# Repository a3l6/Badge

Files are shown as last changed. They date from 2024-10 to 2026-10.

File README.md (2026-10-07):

# Hack Canada Badge — v2 (RP2040 + E-Paper)

This was the first serious attempt at the Hack Canada badge before the design was later simplified into the battery-free NFC badges of v3 and v4.

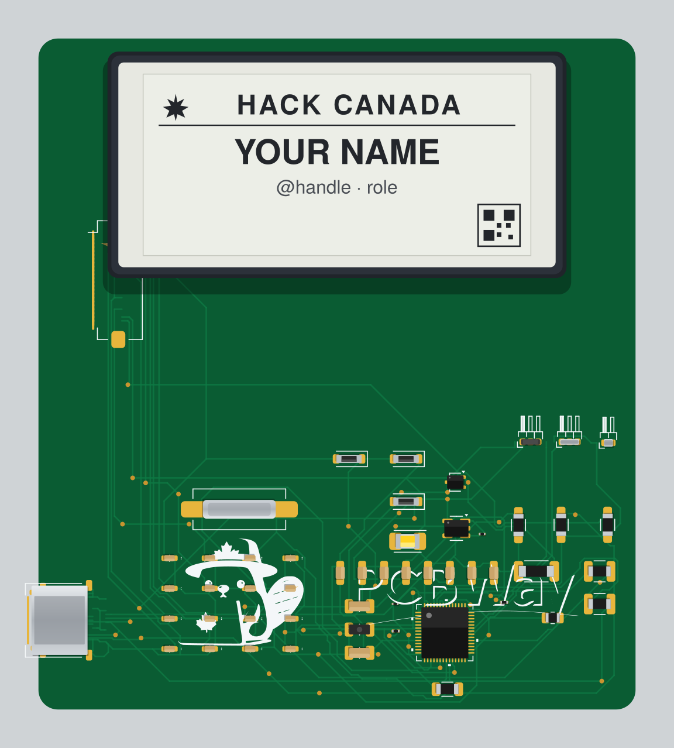
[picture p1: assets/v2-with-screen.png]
v2 badge — fully assembled with the e-paper display mounted


> The main render shows all 51 components placed at their real board positions with the 2.13" e-paper panel mounted on top. Renders are generated from this version's Gerber files (`pcb/prod/gerber/`); colours and the on-screen layout are illustrative.

---

## What it is

Where the later revisions stripped everything down to a passive NFC tag, v2 aimed high: a programmable badge with a screen you could actually put graphics and text on. It's essentially a tiny RP2040 development board in badge form, with an e-paper panel, USB-C for power and programming, and external flash for firmware and assets.

## How it works

```
USB-C ──► RP2040 ──► SPI ──► 2.13" e-paper display (GDEY0213F51)
            │
            ├──► QSPI ──► W25Q32 flash (firmware + images)
            ├──► 12 MHz crystal
            ├──► BOOT + RESET buttons, SWD header
            └──► status LED
```

Plug it in over USB-C, flash firmware to the RP2040 (BOOTSEL/UF2 or SWD), and drive the e-paper display to show a name, schedule, or artwork. The display holds its image with no power, which suits a badge that spends most of its life idle.

## Core components

| Function | Part |
| --- | --- |
| Microcontroller | RP2040 |
| Display | GDEY0213F51 — 2.13" e-paper / E-Ink (SEEKINK panel) |
| Flash | W25Q32JVSSIQ — 32 Mbit (4 MB) SPI/QSPI |
| Clock | 12 MHz crystal (FC4SDCBMF12.0-T1) |
| Power / data | USB Type-C |
| Indicator | VLMC3100-GS08 LED |
| Protection | LESD5D5.0CT1G TVS/ESD diodes |
| Controls | BOOT + RESET buttons, SWD debug header |

## Board

| Spec | Value |
| --- | --- |
| Dimensions | 77.05 × 86.55 mm |
| Layers | 2 |
| Thickness | 1.6 mm |
| Designed in | KiCad 8 |

| Front | Back |
| --- | --- |
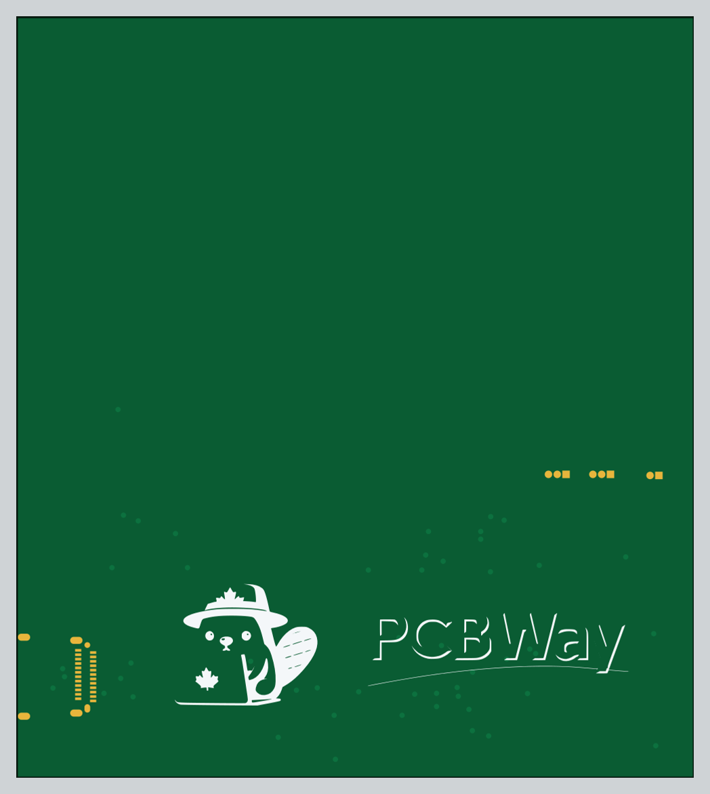
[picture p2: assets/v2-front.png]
Front
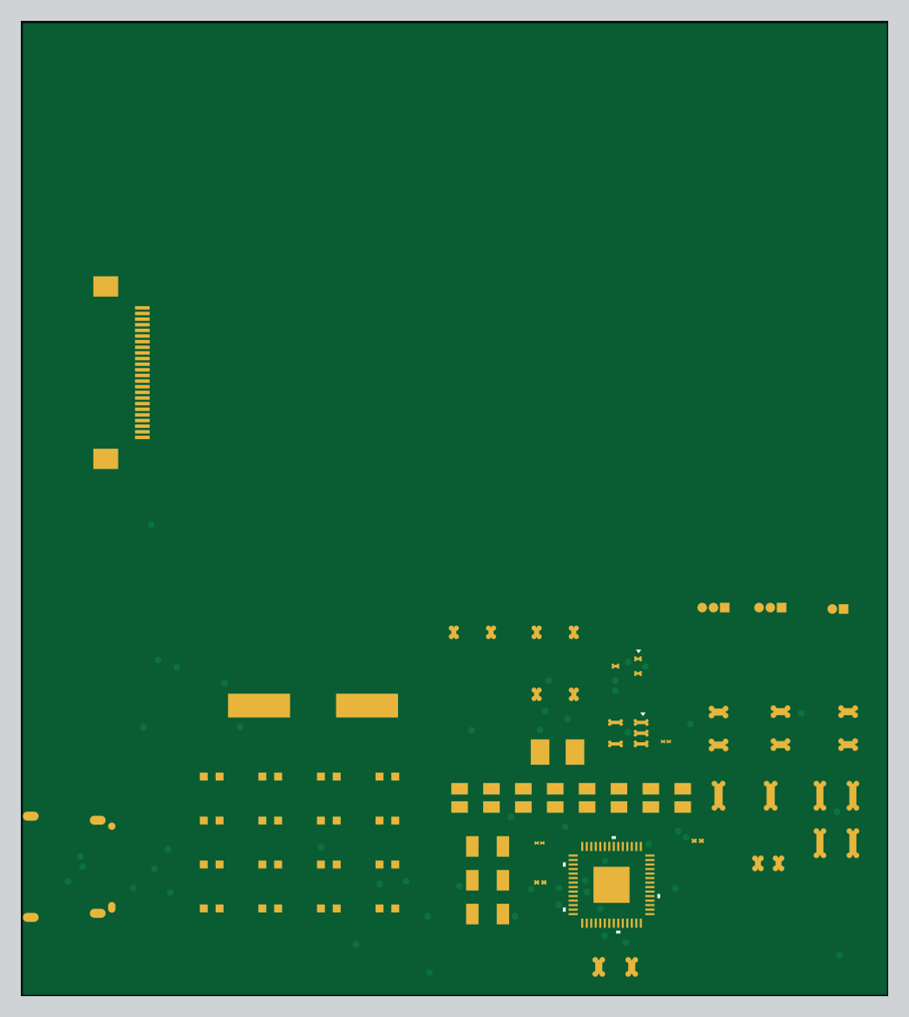
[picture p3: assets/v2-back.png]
Back
|  |  |

### Assembled (parts placed)

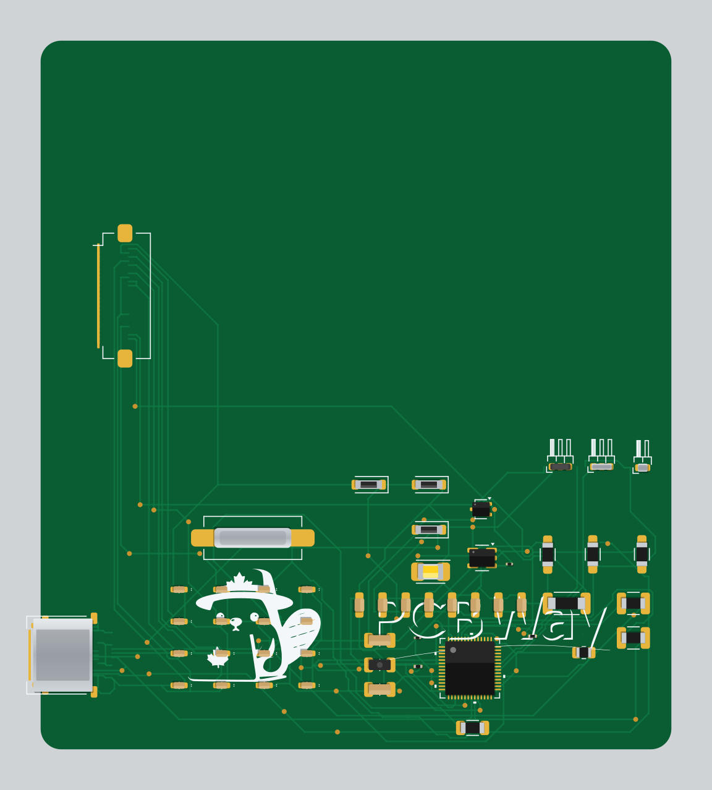
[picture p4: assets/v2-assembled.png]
v2 badge assembled


The e-paper panel (shown mounted in the main image at the top) connects over the FPC ribbon connector at the upper-left and sits above the board across the open top area, with the RP2040 and power circuitry tucked below it. The on-screen layout in that render is a placeholder mock-up, not artwork from the repo.

## Repository layout (v2 branch)

```
pcb/
├── badge.kicad_pcb / .kicad_sch / .kicad_pro   # main design
├── prod/gerber/                                # Gerbers, drills, gbrjob — ready to fab
├── badge-backups/                              # KiCad auto-backups
├── <component>/                                # per-part symbol/footprint/3D libraries
│   (RP2040, W25Q32, GDEY0213F51, crystal, LEDs, TVS, caps …)
└── assets/                                     # logos
GDEY0213F51.kicad_sym                           # e-paper display symbol
README.md
```

## Building your own

1. **Fabricate:** send `pcb/prod/gerber/` (or `badge-gerbers-and-designs.zip`) to your board house. It's a 2-layer, 1.6 mm board.
2. **Edit:** open `pcb/badge.kicad_pro` in KiCad 8 to modify the layout or schematic.
3. **Assemble & flash:** populate the parts, power over USB-C, and load RP2040 firmware via UF2 (BOOTSEL) or the SWD header. Then drive the GDEY0213F51 over SPI.

## History

v2 → **v3** (pivot to a battery-free NFC badge, adopted from the open "Opentaxus" design) → **v4** (streamlined 4-part NFC badge). See the `v3` and `v4` branches / READMEs.

## License

No license file is included, so all rights are reserved by default. Contact [@a3l6](https://github.com/a3l6) to discuss reuse.

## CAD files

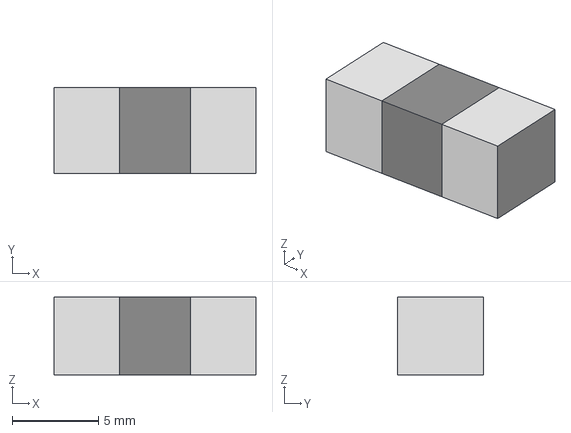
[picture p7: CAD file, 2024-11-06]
pcb/FC4SDCBMF12.0-T1/CRYSTAL_HC49SDLF_FXT.step
11.7 x 5.00 x 4.50 mm

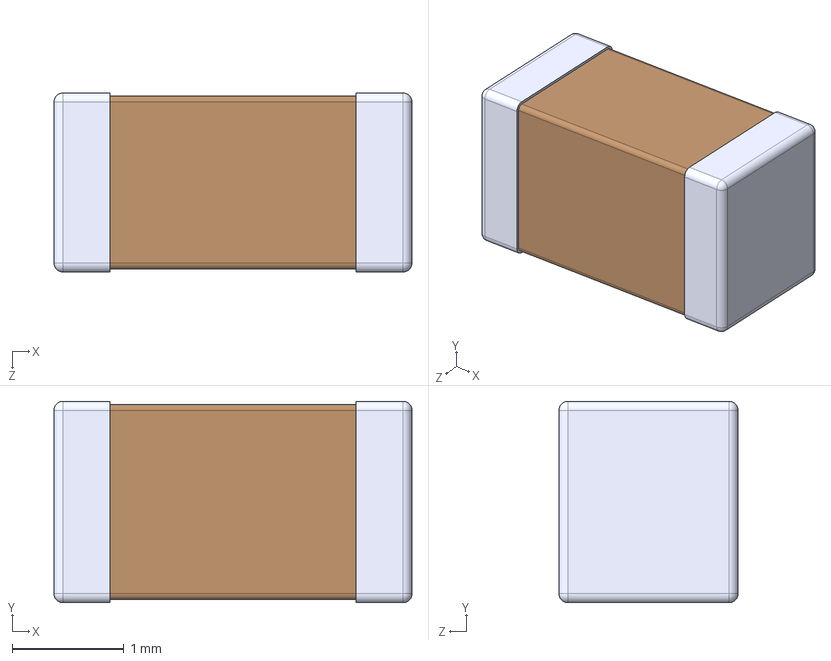
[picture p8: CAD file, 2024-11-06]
pcb/GMK316AB7475KLHT/3D/GMK316AB7475KLHT.stp
3.20 x 1.80 x 1.60 mm

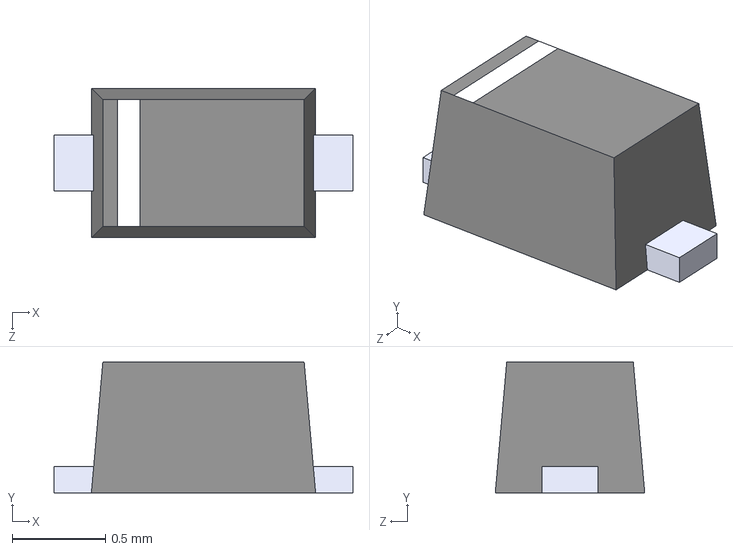
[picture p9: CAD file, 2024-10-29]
pcb/LESD5D5.0CT1G.step
1.60 x 0.7 x 0.8 mm

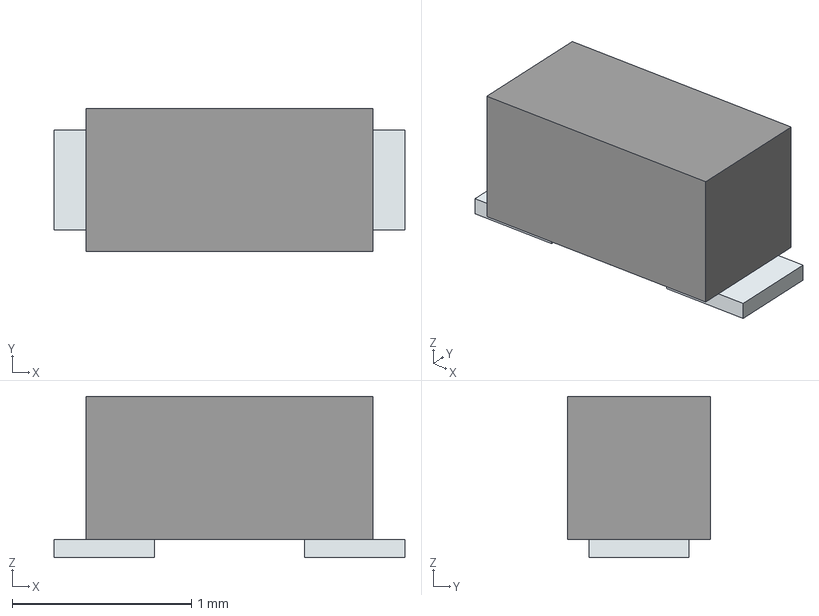
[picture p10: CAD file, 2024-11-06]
pcb/MAJCT168BB7105KTEA01/3D/MAJCT168BB7105KTEA01.stp
1.96 x 0.8 x 0.9 mm
Pins

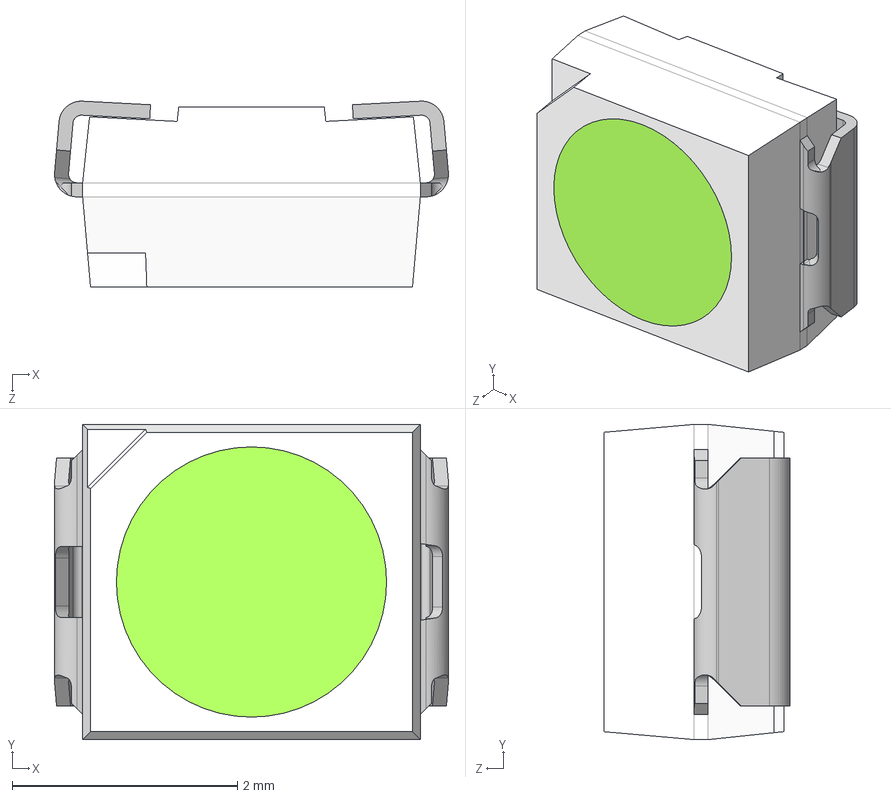
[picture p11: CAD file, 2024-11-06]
pcb/VLMC3100-GS08/3D/VLMC3100-GS08.stp
3.50 x 2.80 x 1.65 mm

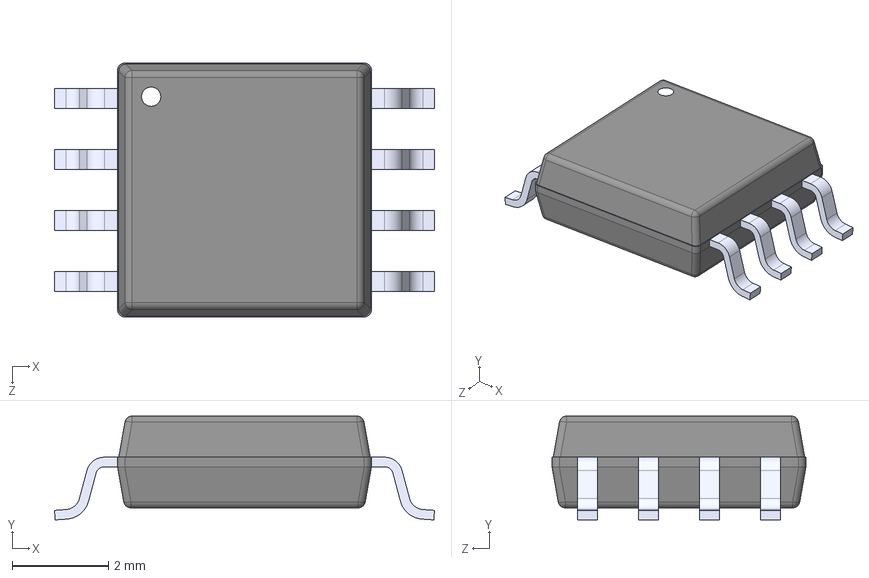
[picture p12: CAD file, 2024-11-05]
pcb/W25Q32JVSSIQ/W25Q32JVSSIQ.step
7.90 x 2.16 x 5.28 mm

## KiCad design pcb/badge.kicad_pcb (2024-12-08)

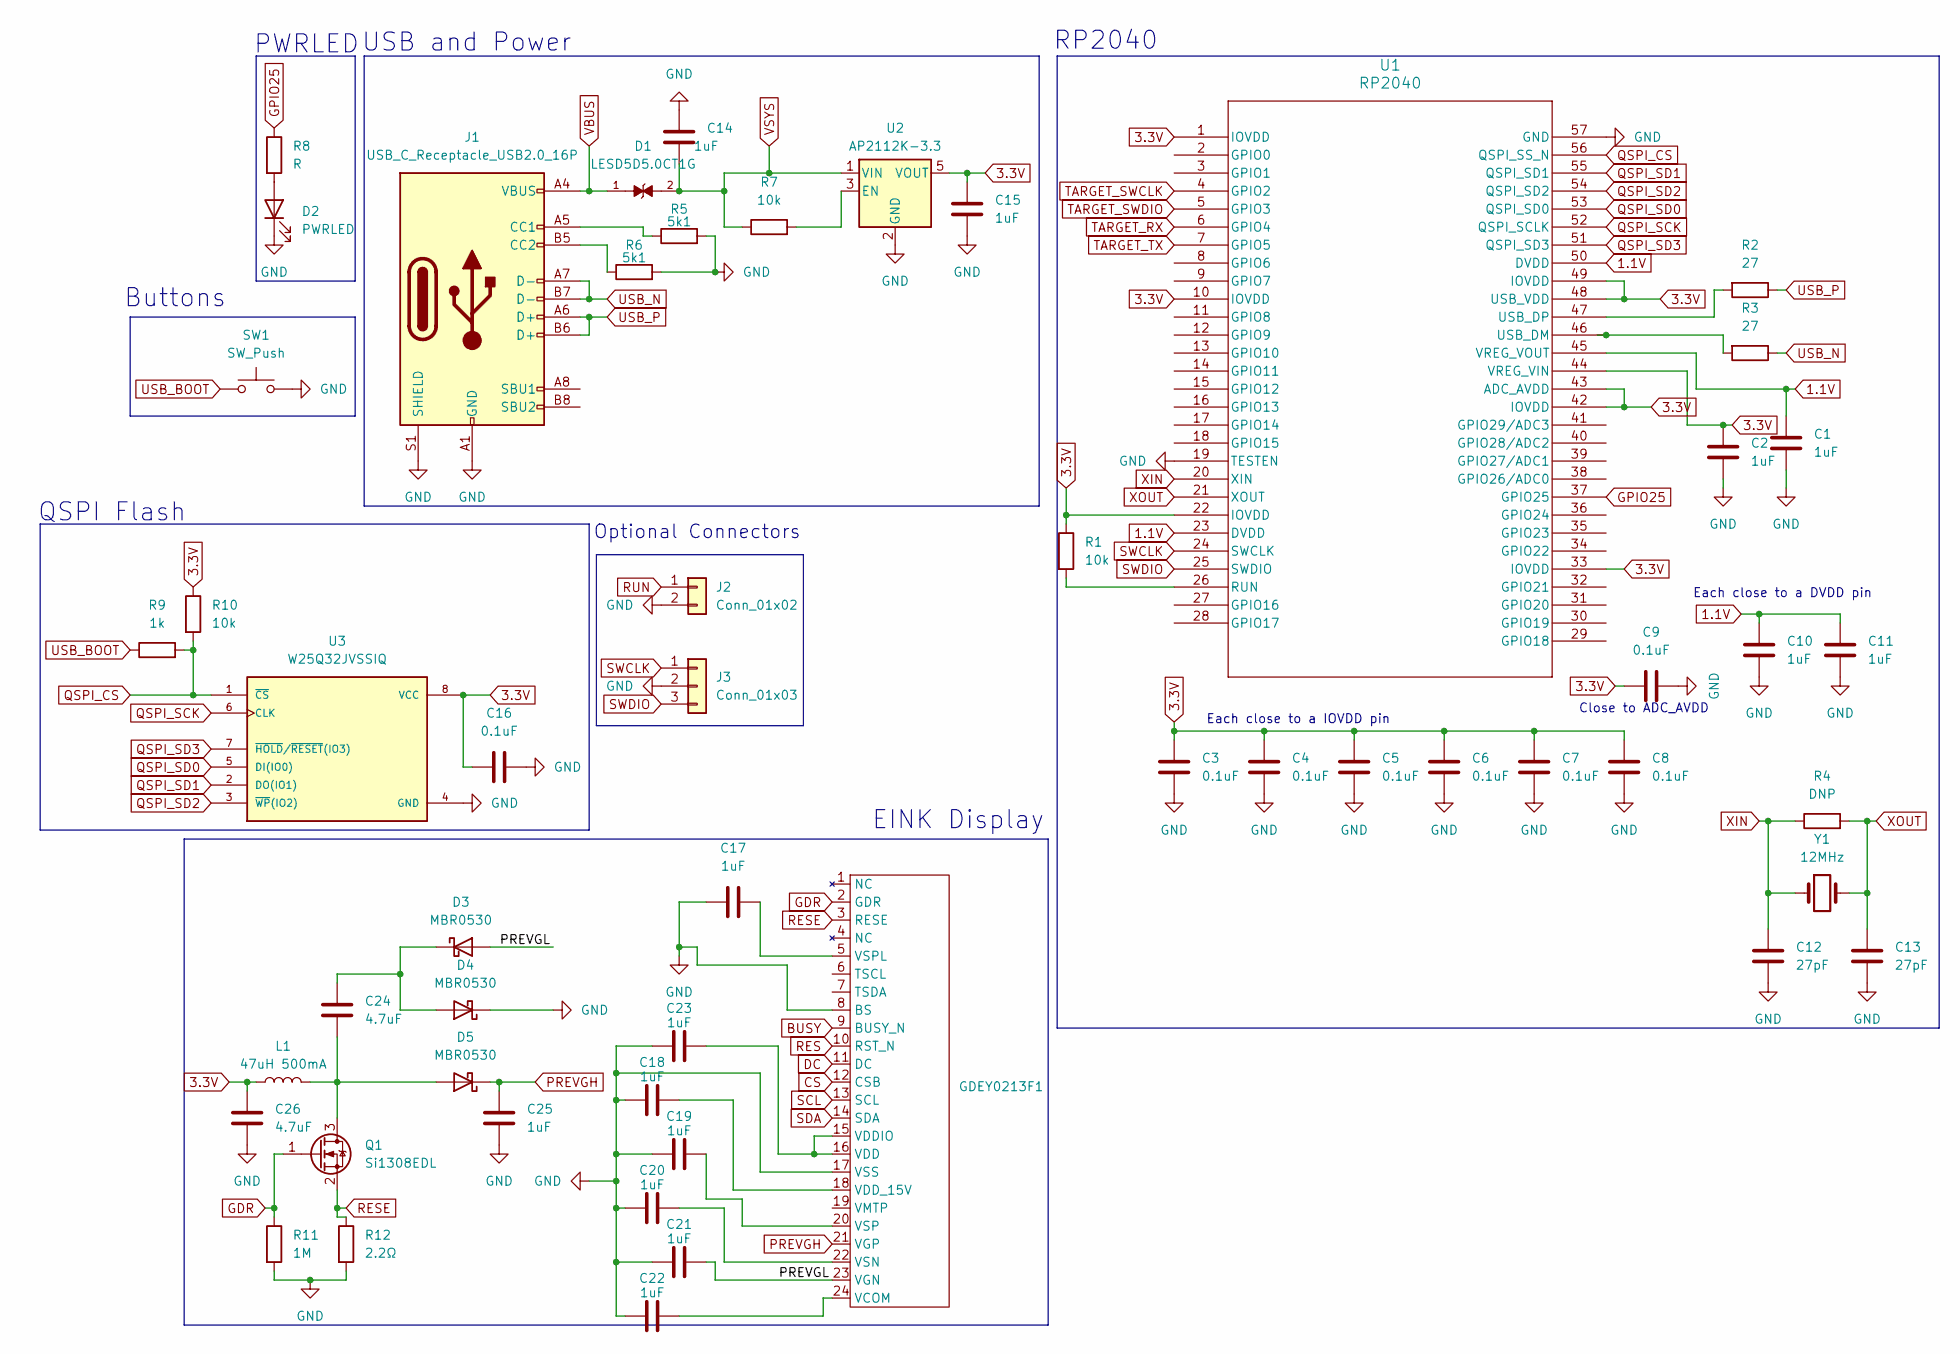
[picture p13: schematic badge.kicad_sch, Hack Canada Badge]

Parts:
C1, C2, C10, C11, C14, C15, C17, C18, C19, C20, C21, C22, C23, C25: 1uF; MAJx16
C3, C4, C5, C6, C7, C8, C9, C16: 0.1uF; CAPC2012X94N
C12, C13: 27pF; MAJx16
C24, C26: 4.7uF; CAPC3216X180N
D1: LESD5D5.0CT1G; TVS_LESD5D5.0CT1G; PARTREV O
D2: PWRLED; LEDM3528X185N
D3, D4, D5: MBR0530; D_SOD-123
GDEY0213F1: (no value)
J1: USB_C_Receptacle_USB2.0_16P; USB_C_Receptacle_Amphenol_12401610E4-2A
J2: Conn_01x02; PinHeader_1x02_P1.00mm_Horizontal
J3: Conn_01x03; PinHeader_1x03_P1.00mm_Horizontal
L1: 47uH 500mA; PinHeader_1x03_P1.00mm_Horizontal
Q1: Si1308EDL; SOT-323_SC-70
R1, R7, R10: 10k
R2, R3: 27
R4: DNP
R5, R6: 5k1
R8: R
R9: 1k
R11: 1M
R12: 2.2Ω
SW1: SW_Push
U1: RP2040; IC57_RP2040
U2: AP2112K-3.3; SOT-23-5
U3: W25Q32JVSSIQ; SOIC127P790X216-8N; M_PART_NUMBER W25QXX
Y1: 12MHz

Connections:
1.1V: C1.1, C10.1, C11.1, U1.23 (DVDD), U1.45 (VREG_VOUT), U1.50 (DVDD)
3.3V: C2.1, C3.1, C4.1, C5.1, C6.1, C7.1, C8.1, C9.1, C15.1, C16.1, C26.1, L1.1, R1.1, R10.1, U1.1 (IOVDD), U1.10 (IOVDD), U1.22 (IOVDD), U1.33 (IOVDD), U1.42 (IOVDD), U1.43 (ADC_AVDD), U1.44 (VREG_VIN), U1.48 (USB_VDD), U1.49 (IOVDD), U2.5 (VOUT), U3.8 (VCC)
/PREVGL: C21.2, D3.2 (A), GDEY0213F1.23 (VGN)
BUSY: GDEY0213F1.9 (BUSY_N)
CS: GDEY0213F1.12 (CSB)
DC: GDEY0213F1.11 (DC)
GDR: GDEY0213F1.2 (GDR), Q1.1 (G), R11.1
GND: C1.2, C2.2, C3.2, C4.2, C5.2, C6.2, C7.2, C8.2, C9.2, C10.2, C11.2, C12.2, C13.2, C14.1, C15.2, C16.2, C17.1, C18.1, C19.1, C20.1, C21.1, C22.1, C23.1, C25.2, C26.2, D2.1 (K), D4.1 (K), GDEY0213F1.8 (BS), GDEY0213F1.17 (VSS), J1.A1 (GND), J1.A12 (GND), J1.B1 (GND), J1.B12 (GND), J1.S1 (SHIELD), J2.2, J3.2, R5.2, R6.2, R11.2, R12.2, SW1.2, U1.19 (TESTEN), U1.57 (GND), U2.2 (GND), U3.4 (GND)
GPIO25: R8.1, U1.37 (GPIO25)
unnamed: D2.2 (A), R8.2
unnamed: C24.1, D3.1 (K), D4.2 (A)
unnamed: C24.2, D5.2 (A), L1.2, Q1.3 (D)
unnamed: C22.2, GDEY0213F1.24 (VCOM)
unnamed: C23.2, GDEY0213F1.15 (VDDIO), GDEY0213F1.16 (VDD)
unnamed: C18.2, GDEY0213F1.18 (VDD_15V)
unnamed: C20.2, GDEY0213F1.22 (VSN)
unnamed: C19.2, GDEY0213F1.20 (VSP)
unnamed: C17.2, GDEY0213F1.5 (VSPL)
unnamed: J1.A5 (CC1), R5.1
unnamed: J1.B5 (CC2), R6.1
unnamed: R1.2, U1.26 (RUN)
unnamed: R3.2, U1.46 (USB_DM)
unnamed: R2.2, U1.47 (USB_DP)
unnamed: R7.2, U2.3 (EN)
PREVGH: C25.1, D5.1 (K), GDEY0213F1.21 (VGP)
QSPI_CS: R9.2, R10.2, U1.56 (QSPI_SS_N), U3.1 (~CS)
QSPI_SCK: U1.52 (QSPI_SCLK), U3.6 (CLK)
QSPI_SD0: U1.53 (QSPI_SD0), U3.5 (DI(IO0))
QSPI_SD1: U1.55 (QSPI_SD1), U3.2 (DO(IO1))
QSPI_SD2: U1.54 (QSPI_SD2), U3.3 (~WP(IO2))
QSPI_SD3: U1.51 (QSPI_SD3), U3.7 (~HOLD/~RESET(IO3))
RES: GDEY0213F1.10 (RST_N)
RESE: GDEY0213F1.3 (RESE), Q1.2 (S), R12.1
RUN: J2.1
SCL: GDEY0213F1.13 (SCL)
SDA: GDEY0213F1.14 (SDA)
SWCLK: J3.1, U1.24 (SWCLK)
SWDIO: J3.3, U1.25 (SWDIO)
TARGET_RX: U1.6 (GPIO4)
TARGET_SWCLK: U1.4 (GPIO2)
TARGET_SWDIO: U1.5 (GPIO3)
TARGET_TX: U1.7 (GPIO5)
USB_BOOT: R9.1, SW1.1
USB_N: J1.A7 (D-), J1.B7 (D-), R3.1
USB_P: J1.A6 (D+), J1.B6 (D+), R2.1
VBUS: D1.1, J1.A4 (VBUS), J1.A9 (VBUS), J1.B4 (VBUS), J1.B9 (VBUS)
VSYS: C14.2, D1.2, R7.1, U2.1 (VIN)
XIN: C12.1, R4.1, U1.20 (XIN), Y1.1
XOUT: C13.1, R4.2, U1.21 (XOUT), Y1.2

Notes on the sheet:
EINK Display
USB and Power
Optional Connectors
Close to ADC_AVDD
Each close to a IOVDD pin
Buttons
Each close to a DVDD pin
RP2040
PWRLED
QSPI Flash

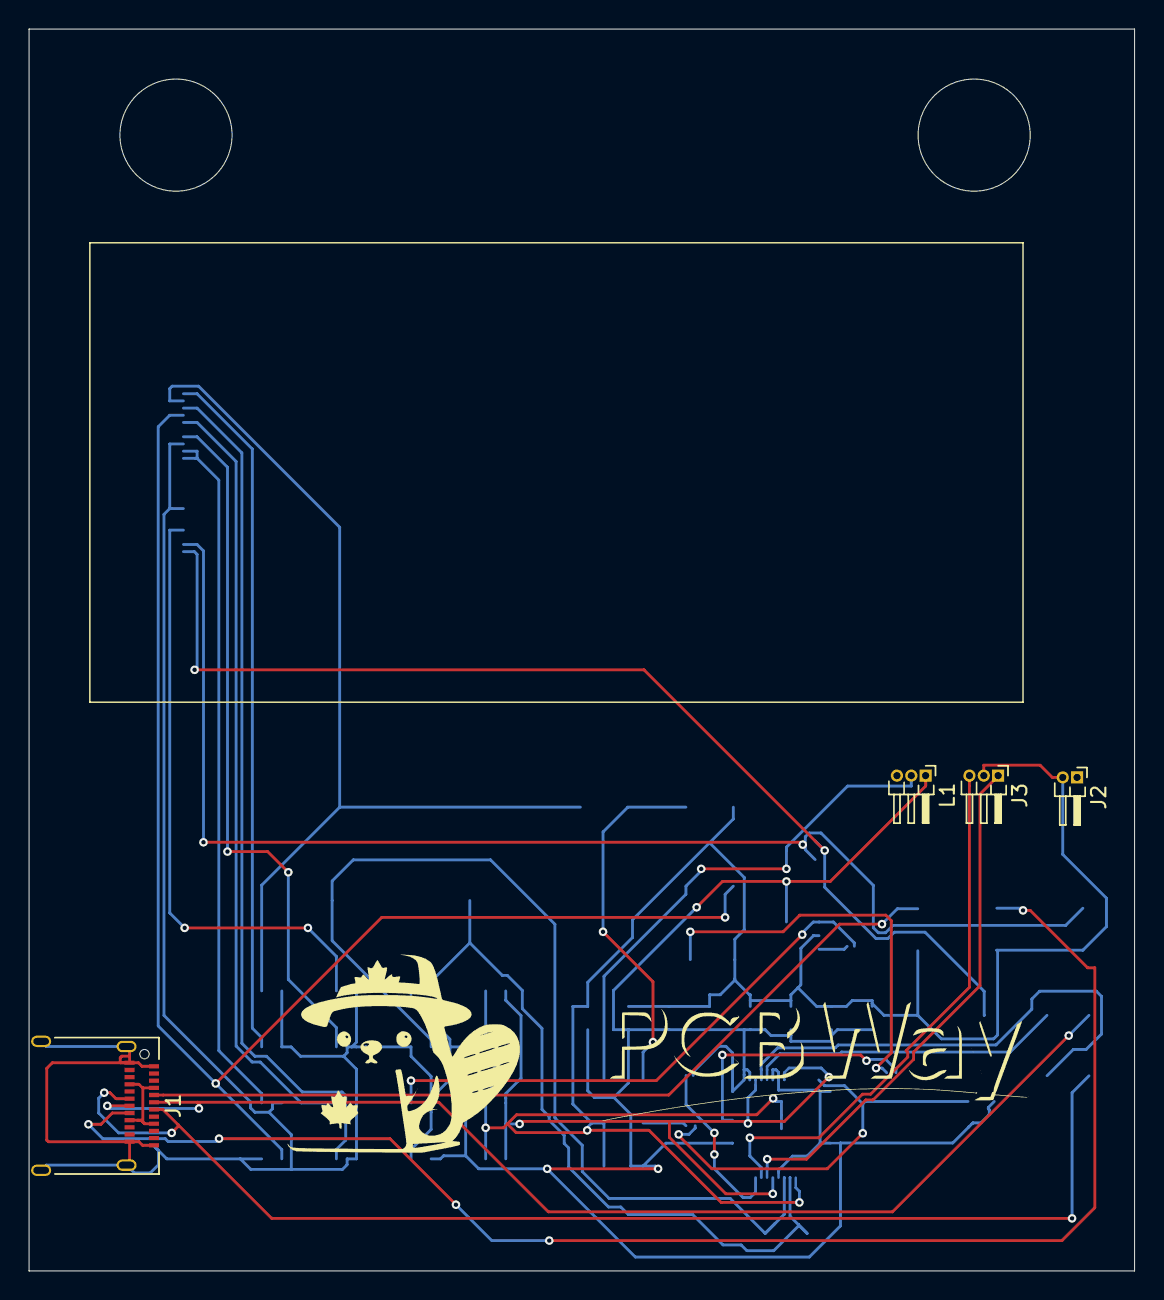
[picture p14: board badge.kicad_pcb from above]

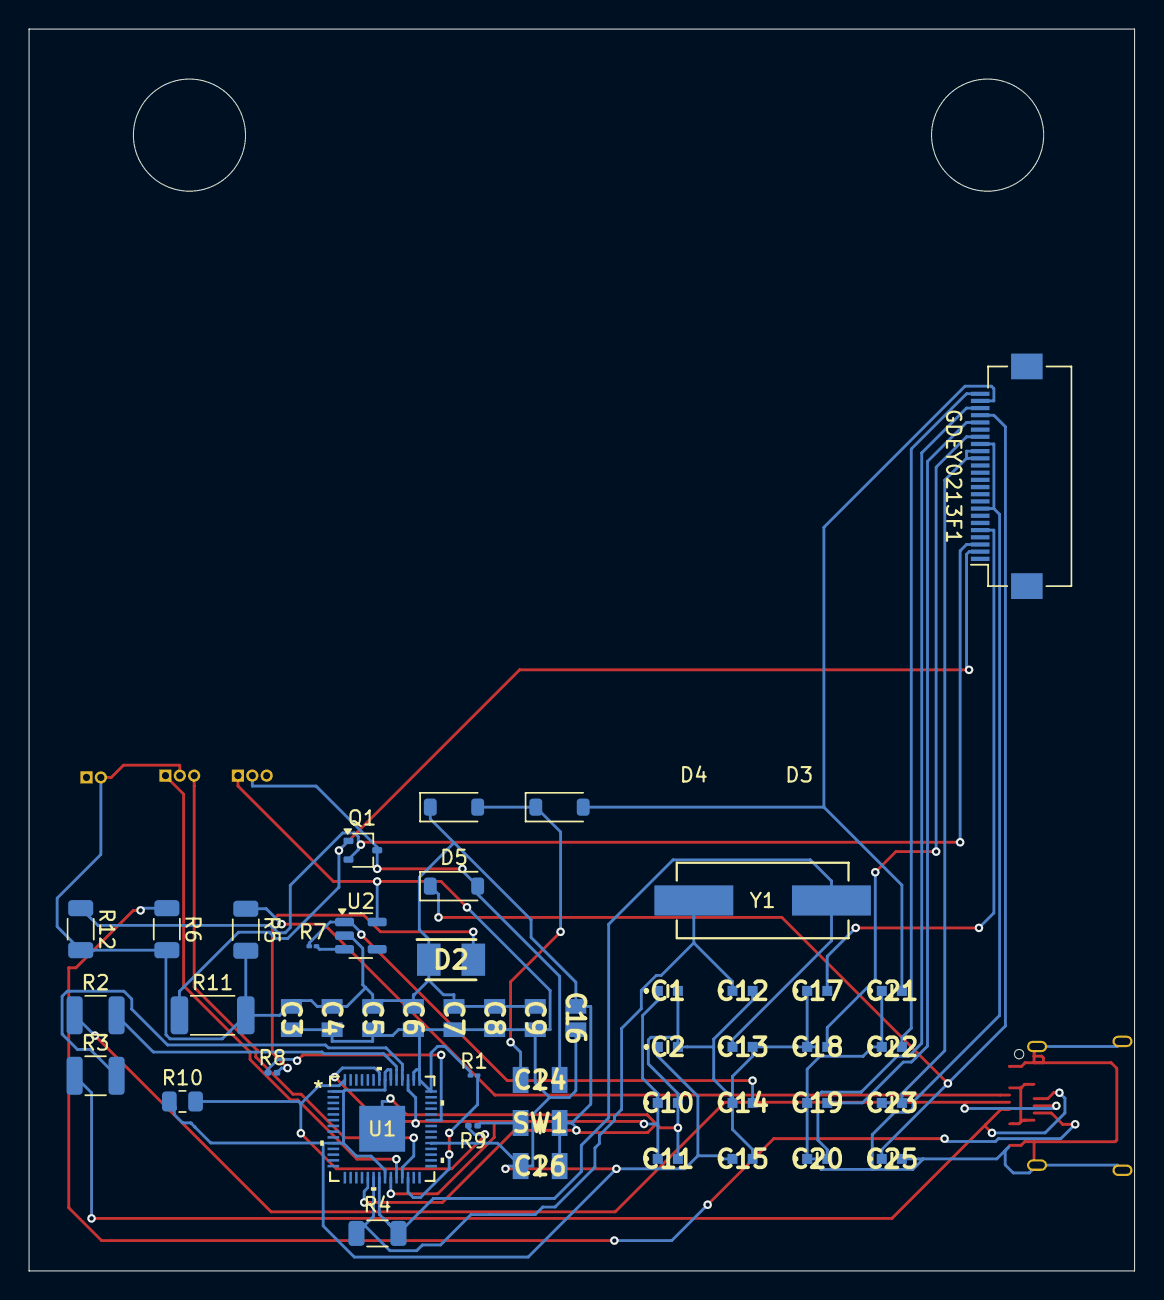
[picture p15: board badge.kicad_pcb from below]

Board: 2 copper layers, 77.0 x 86.5 mm, 52 parts (48 on the bottom side), 33 nets.

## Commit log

2024-10-26 Began routing for esp32
    [badge.kicad_pcb, badge.kicad_sch]
2024-10-29 Finished USB-C and ESP32 schematic
    [LESD5D5.0CT1G.step, badge.kicad_sch]
2024-10-31 Made symbol for GDEY0213F51
    [badge.kicad_sch]
2024-11-01 Began changing to rp2040
    [badge.kicad_sch]
2024-11-05 Beginning to get footprints
    [W25Q32JVSSIQ.step, badge.kicad_sch]
2024-11-06 Began schematic
    [CRYSTAL_HC49SDLF_FXT.step, badge.kicad_pcb, badge.kicad_sch]
2024-11-06 Saving before autorouting
    [badge.kicad_pcb]
2024-11-06 More footprints
    [GMK316AB7475KLHT.stp, MAJCT168BB7105KTEA01.stp, VLMC3100-GS08.stp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]
2024-11-07 Finished routing
    [badge.kicad_pcb]
2024-12-08 Added sketches
    [badge-B_Cu.gbr, badge-B_Mask.gbr, badge-B_Paste.gbr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]
2026-07-27 Add README with board renders, assembled view, and e-paper mockup
2026-07-27 Fix library folder name containing newline characters (breaks Windows clone/ZIP)
    [MAJCT168BB7105KTEA01.stp]
2026-07-28 Use assembled + e-paper render as the main README image
2026-10-07 Update README to simplify assembled components section
    Removed redundant description about assembled components.
